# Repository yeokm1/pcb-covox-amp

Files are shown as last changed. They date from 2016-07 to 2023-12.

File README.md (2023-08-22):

# pcb-covox-amp
A tiny sound card based on the Covox Speech Thing design which includes an LM386 amplifier. I have another design that just has the resistor ladder portion only without the amplifier which can be found [here](https://github.com/yeokm1/pcb-covox).

##PCB Design software and addons used

1. Kicad 4.0.2 or later

## Video

(https://www.youtube.com/watch?v=iOxOxpSg3WE)

Due to copyright problems in the music used, this video can only be viewed on a PC. It is blocked on mobile devices and other platforms.

## Images
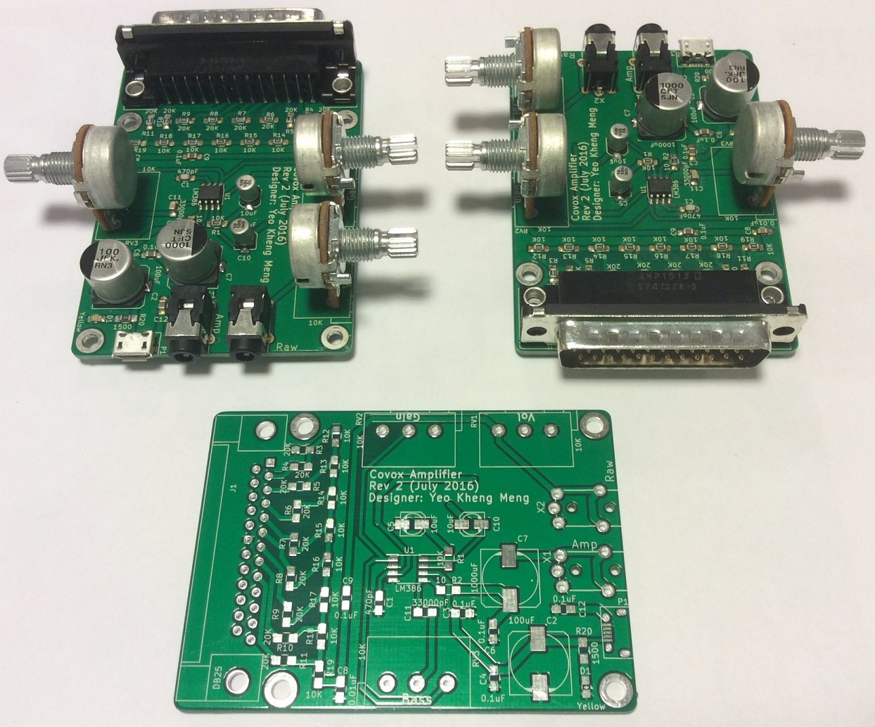
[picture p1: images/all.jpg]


The picture is of the Rev 2 version with the bug in the limited parallel port grounding. This has been corrected in the Rev 3 gerber but not fabricated.

##Schematic drawings

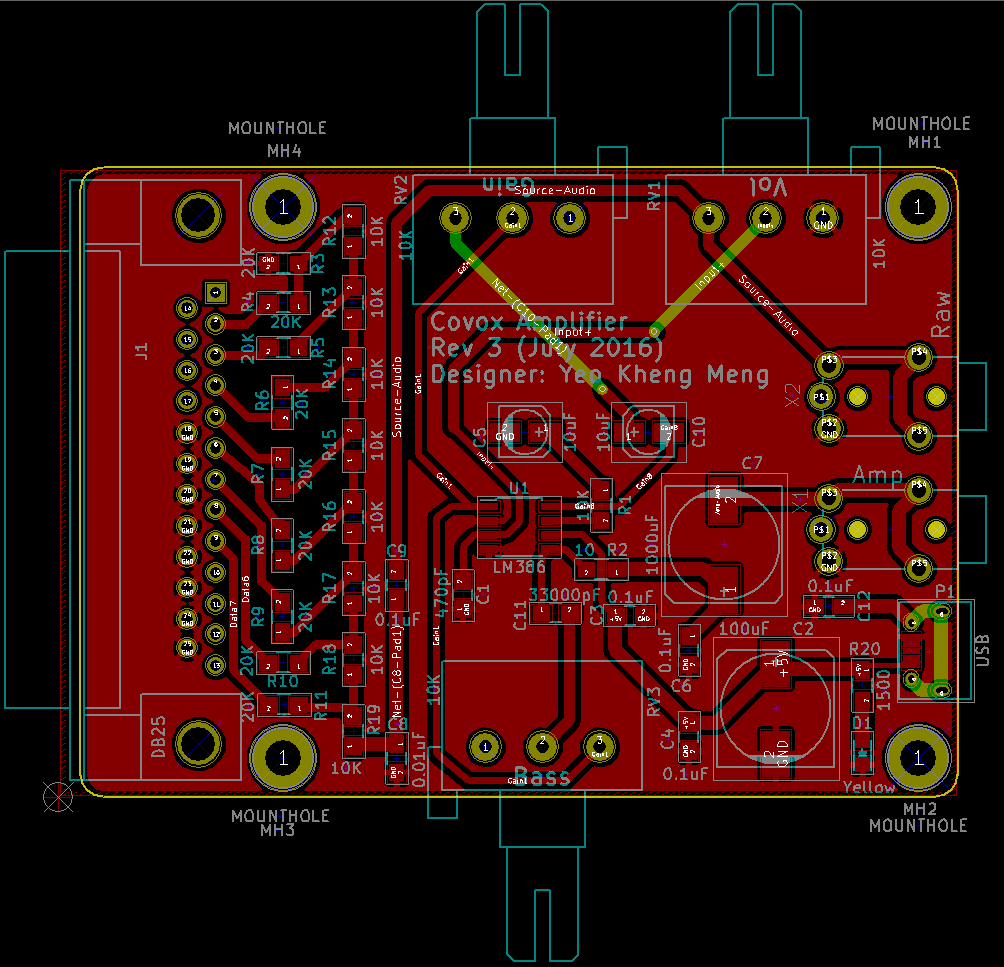
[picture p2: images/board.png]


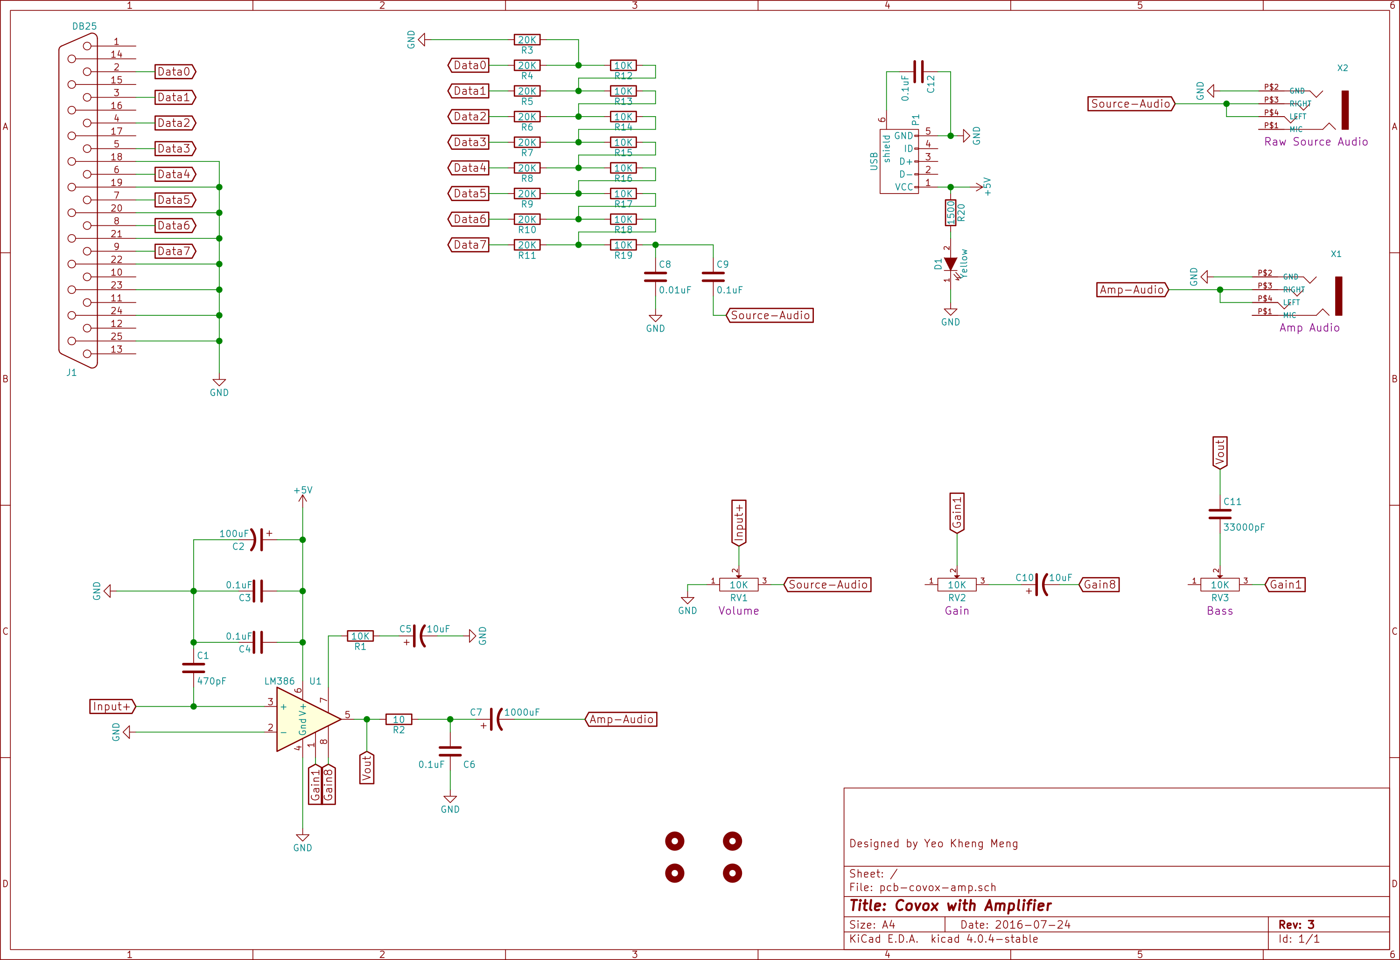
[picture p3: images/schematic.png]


## Parts required
Use Libreoffice to open [pcb-covox-amp-bom.ods](pcb-covox-amp-bom.ods)

## Errata

As reported in this [issue](https://github.com/yeokm1/pcb-covox-amp/issues/2), there is a mistake in components R2 and C6. As I'm not currently using this project, I'll not be correcting this error.

## References
1. [Hardware implementation references](https://blog.frantovo.cz/c/307/DAC%20%28zvukov%C3%A1%20karta%29%20pro%20LPT%20port%20a.k.a.%20Covox)
2. [Design reference](http://kb.gr8bit.ru/KB0010/GR8BIT-KB0010-Adding-multimedia-capability-covox-device.html)
3. [MJ-2135 package referenced from coqui-dip](https://github.com/open-eie/coqui-dip)
4. [Amplifier circuit](http://www.circuitbasics.com/build-a-great-sounding-audio-amplifier-with-bass-boost-from-the-lm386/)

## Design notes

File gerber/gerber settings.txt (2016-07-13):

Obtained from https://forum.kicad.info/t/creating-gerberfiles/1356/8

[plots]
plot format: gerber

layers:
F.Cu
B.Cu
B.SilkS
F.SilkS
B.Mask
F.Mask
Edge.Cuts
B.Paste (for stencil)
F.Paste (for stencil)

options:
Exclude PCB edge layer from other layers

gerber options:
Use Protel filename extensions
Include extended attributes

default line width (mm):
0.1

format:
4.6 (mm)

[drill file]
drill units:
Millimeters

zeroes format:
Decimal format

drill map file format:
Gerber

drill file options:
none (DESELECT merging of PTH and NPTH)

drill origin:
Absolute

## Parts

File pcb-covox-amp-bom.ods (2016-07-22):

Designator | Device | Package | Designation | Manufacturer | Part Number | Quantity | Unit Cost | Total Unit Cost | Source webpage
- | PCB Fabrication with stencil | 10cm x 10cm | HASL Lead free | Elecrow | - | 1 | 14 | 14 | http://www.elecrow.com/5pcs-2-layer-pcb-p-1174.html
C1 | SMD Multilayer Ceramic Capacitor | C_0805_HandSoldering | 470pF | AVX | 08055A471JAT2A | 1 | 0.162 | 0.162 | http://sg.element14.com/avx/08055a471jat2a/cap-mlcc-c0g-np0-470pf-50v-0805/dp/1612188
C3,C4,C6,C9,C12 | SMD Multilayer Ceramic Capacitor, MCU Series | C_0805_HandSoldering | 0.1uF | Multicomp | MCU0805F104ZCT | 5 | 0.008 | 0.04 | http://sg.element14.com/multicomp/mcu0805f104zct/cap-mlcc-y5v-100nf-50v-0805/dp/9406409RL
C8 | SMD Multilayer Ceramic Capacitor | C_0805_HandSoldering | 0.01uF | AVX | 08055C103KAT2A | 1 | 0.049 | 0.049 | http://sg.element14.com/avx/08055c103kat2a/cap-mlcc-x7r-10nf-50v-0805/dp/499225
C11 | SMD Multilayer Ceramic Capacitor | C_0805_HandSoldering | 33000pF | AVX | 08051C333KAT2A | 1 | 0.076 | 0.076 | http://sg.element14.com/avx/08051c333kat2a/cap-mlcc-x7r-33nf-100v-0805/dp/1833886
C2 | SMD Aluminium Electrolytic Capacitor, AEC-Q200 FT Series | c_elec_10x10.5 | 100uF, 63V | Panasonic Electronic Components | EEEFK1J101P | 1 | 1.49 | 1.49 | http://sg.element14.com/panasonic-electronic-components/eeefk1j101p/cap-alu-elec-100uf-63v-smd/dp/9696040
C5,C10 | SMD Aluminium Electrolytic Capacitor, AEC-Q200 FT Series | c_elec_4x5.3 | 10uF, 10V | Panasonic Electronic Components | EEE1AA100NR | 2 | 0.99 | 1.98 | http://sg.element14.com/panasonic-electronic-components/eee1aa100nr/cap-alu-elec-10uf-10v-smd/dp/2326096
C7 | SMD Aluminium Electrolytic Capacitor, AEC-Q200 FT Series | c_elec_10x10.5 | 1000uF, 16V | Panasonic Electronic Components | EEEFT1C102AP | 1 | 1.47 | 1.47 | http://sg.element14.com/panasonic-electronic-components/eeeft1c102ap/cap-alu-elec-1000uf-16v-smd/dp/2065974
J1 | Standard D Sub Connector, AMPLIMITE HD-20 Series, DB, Plug, 25 Contacts, Steel Body, Through Hole | DB25MC | DB25 | TE Connectivity/ AMP | 5747238-2 | 1 | 5.15 | 5.15 | http://sg.element14.com/te-connectivity-amp/5747238-2/d-sub-connector-plug-25pos/dp/2452364
D1 | LED, Yellow Green, SMD, 1.25mm x 1.4mm, 20 mA, 2 V, 575 nm | LED_0805 | Yellow, Green | Dialight | 5988160107F | 1 | 0.657 | 0.657 | http://sg.element14.com/dialight/5988160107f/led-0805-yellow-green-40mcd/dp/1465994
X1, X2 | Phone Audio Connector, Socket, 3.5 mm, 4 Contacts, PCB Mount | mj-2135-MJ-2135 | TRRS | Pro Signal | MJ-2135 | 2 | 3.79 | 7.58 | http://sg.element14.com/pro-signal/mj-2135/connector-rca-jack-3-5mm-tht-4way/dp/1267377
RV1,RV2,RV3 | Rotary Potentiometer | Potentiometer_Alps-RK163-single_15mm | 10K | BI Technologies/ TT Electronics | 16mm | 3 | 1.16 | 3.48 | http://sg.element14.com/bi-technologies-tt-electronics/p160kn-0qd15b10k/rotary-potentiometer-10kohm-16mm/dp/1782728
R1,R12,R13,R14,R15,R16,R17,R18,R19 | Surface Mount Chip Resistor, Thick Film, AEC-Q200 ERJ6E Series | R_0805_HandSoldering | 10K, ±0.5% | Panasonic Electronic Components | ERJ6RBD1002V | 9 | 0.047 | 0.423 | http://sg.element14.com/panasonic-electronic-components/erj6rbd1002v/res-thick-film-10k-0-5-0-1w-0805/dp/2380289
R2 | Thick Film Resistor | R_0805_HandSoldering | 10 | Panasonic Electronic Components | ERJ-6ENF10R0V | 1 | 0.156 | 0.156 | http://sg.element14.com/panasonic-electronic-components/erj-6enf10r0v/sistor-thick-film-10-ohm-125mw/dp/2284223
R3,R4,R5,R6,R7,R8,R9,R10,R11 | Surface Mount Chip Resistor, Thick Film, AEC-Q200 ERJ6E Series | R_0805_HandSoldering | 20K, ±0.5% | Panasonic Electronic Components | ERJ6RBD2002V | 9 | 0.047 | 0.423 | http://sg.element14.com/panasonic-electronic-components/erj6rbd2002v/res-thick-film-20k-0-5-0-1w-0805/dp/2380338
R20 | Thick Film Resistor | R_0805_HandSoldering | 1500 | Multicomp | MC0805S8F1501T5E | 1 | 0.005 | 0.005 | http://sg.element14.com/multicomp/mc0805s8f1501t5e/res-thick-film-1k5-1-0-125w-0805/dp/1632464
U1 | LM386M-1 Audio Power Amplifier, AB, 1 Channel, 325 mW, 4V to 12V | SOIC8 | LM386 | Texas Instruments | LM386M-1/NOPB | 1 | 1.48 | 1.48 | http://sg.element14.com/texas-instruments/lm386m-1-nopb/amp-power-audio-mono-class-ab/dp/1564701
P1 | USB Connector, Micro USB Type B, USB 2.0, Receptacle, 5 Ways, Surface Mount, Through Hole Mount | USB_Micro-B | Micro-USB | Hirose | ZX62D-B-5PA8(30) | 1 | 1.09 | 1.09 | http://sg.element14.com/webapp/wcs/stores/servlet/ProductDisplay?productId=141569308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
 |  |  |  |  |  |  | Subtotal | 25.711
 |  |  |  |  |  |  | GST 7% | 1.79977
 |  |  |  |  |  |  | Total (SGD) | 27.51077

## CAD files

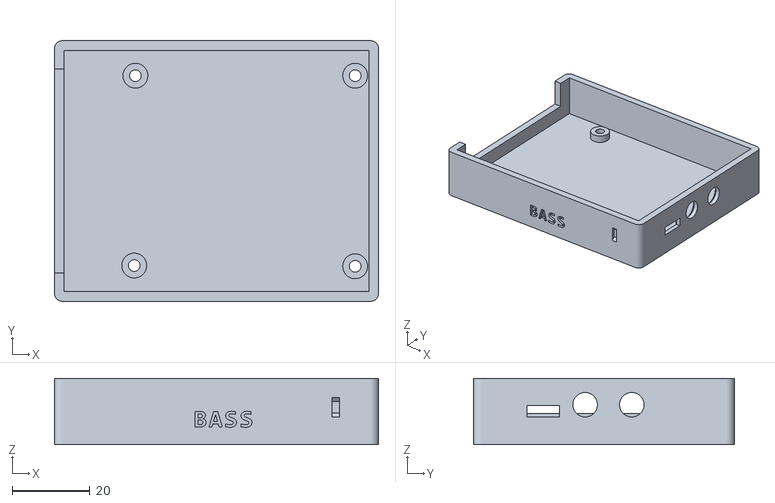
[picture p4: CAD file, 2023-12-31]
3d_printable_case/covox_amp_bottom.stl
83.3 x 67.0 x 17.0

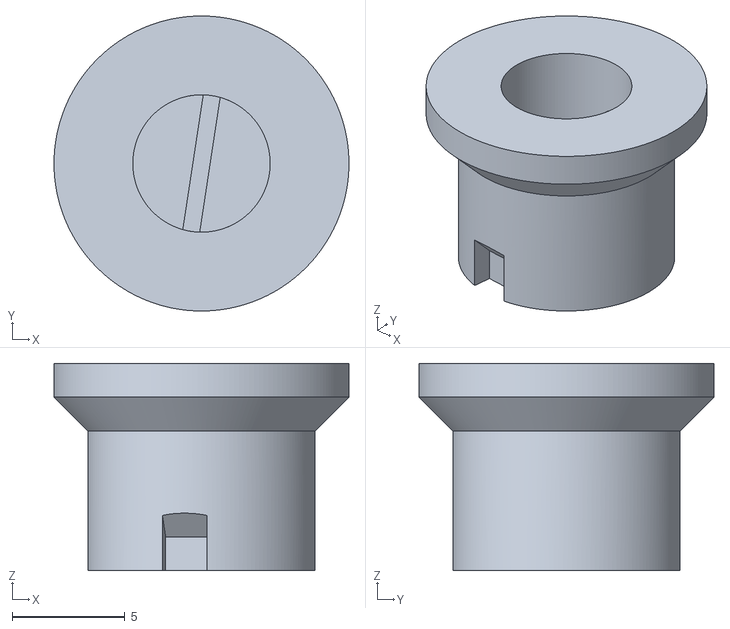
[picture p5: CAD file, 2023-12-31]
3d_printable_case/covox_amp_knob.stl
13.1 x 13.1 x 9.20

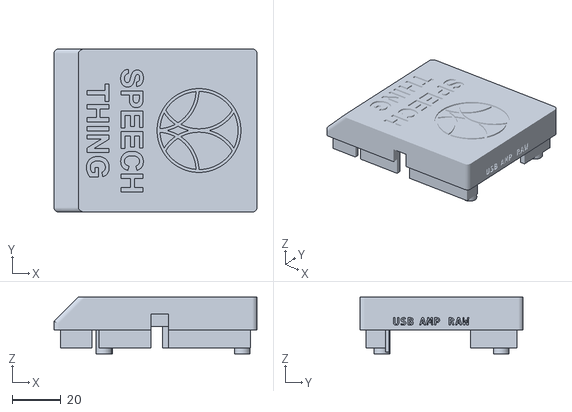
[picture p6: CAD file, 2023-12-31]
3d_printable_case/covox_amp_top.stl
83.3 x 67.0 x 23.4

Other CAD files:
3d_printable_case/covox_amp_3d_model.f3d

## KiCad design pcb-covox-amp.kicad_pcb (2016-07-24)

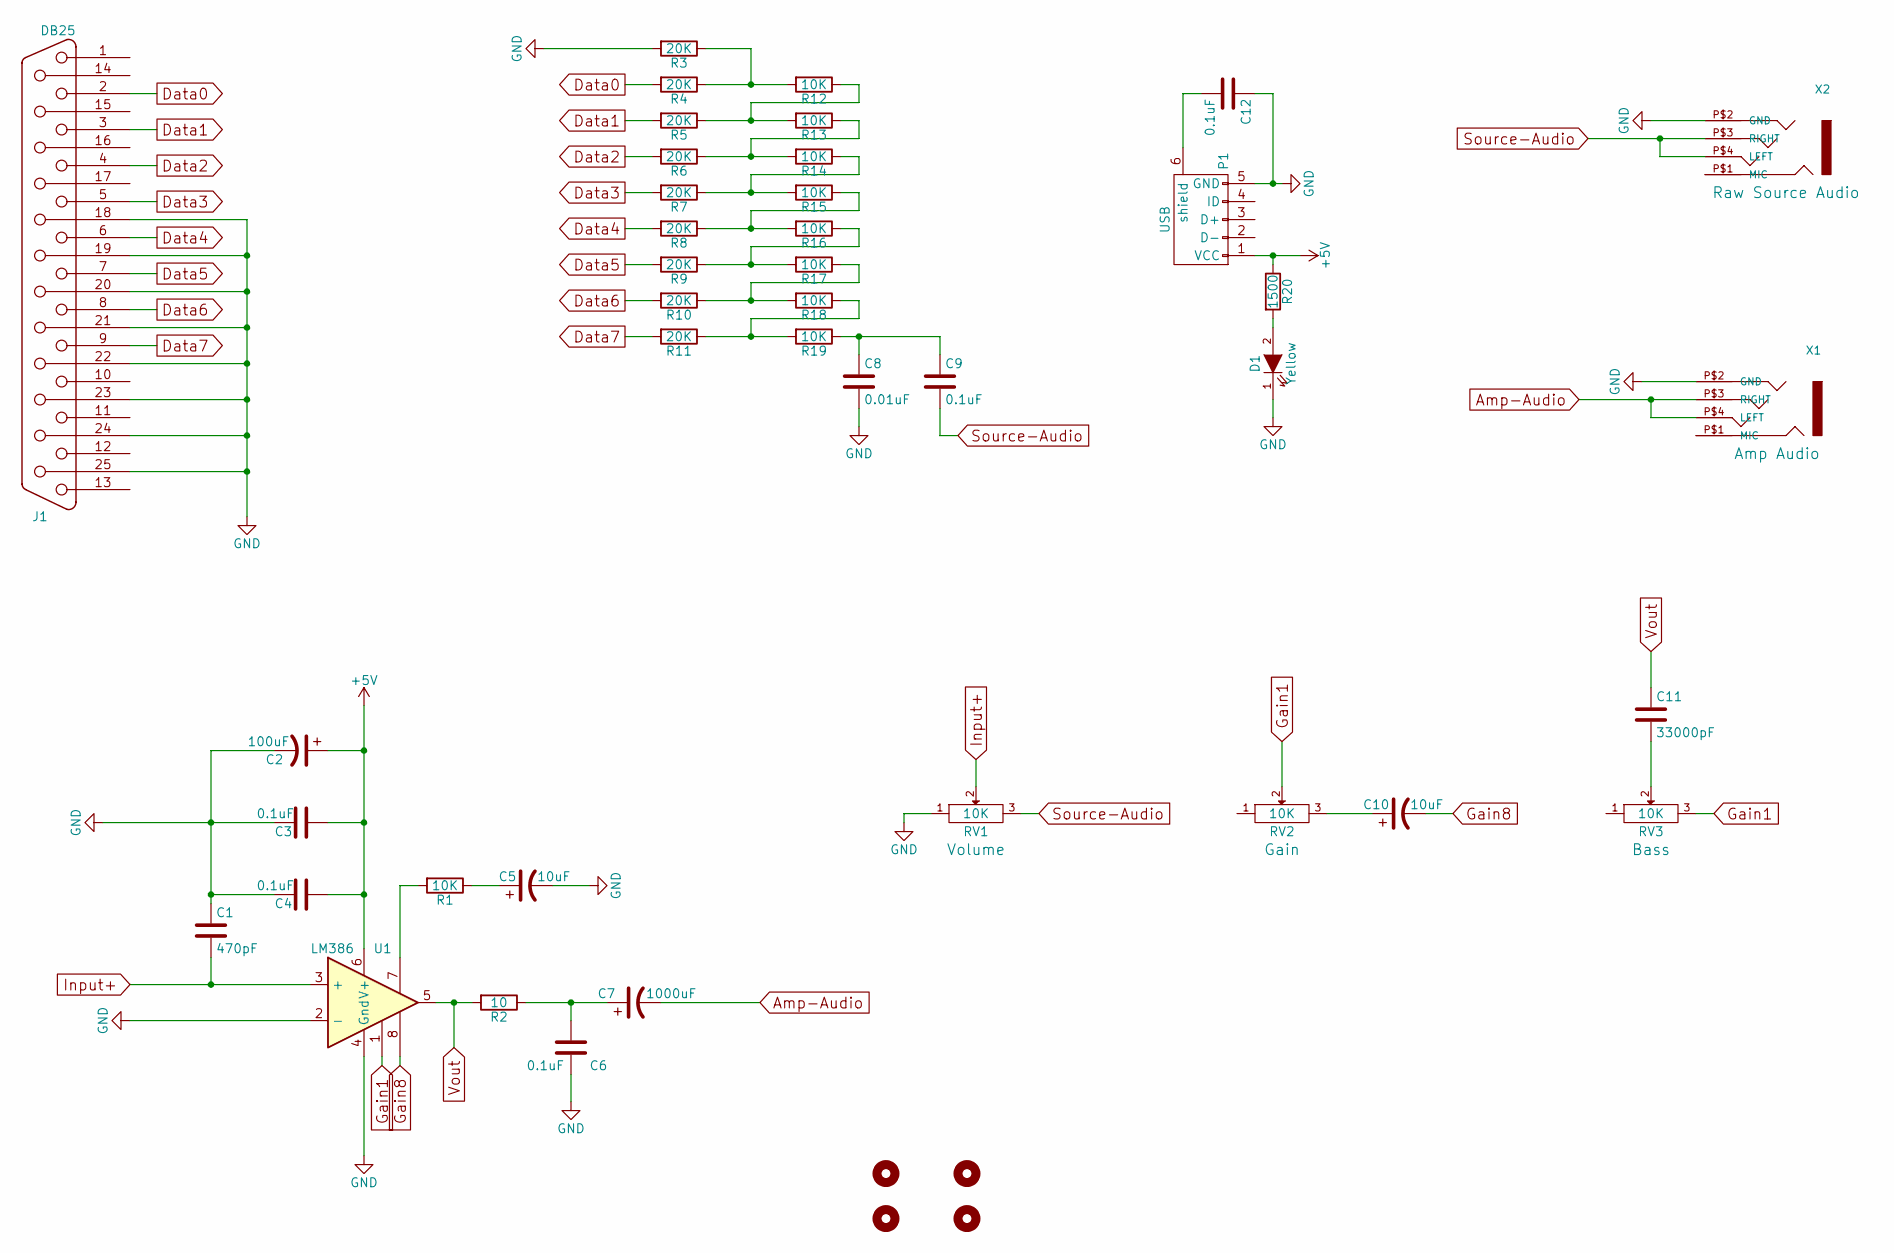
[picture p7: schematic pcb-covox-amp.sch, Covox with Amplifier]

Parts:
C1: 470pF; C_0805_HandSoldering
C2: 100uF; c_elec_10x10.5
C3, C4, C6, C9, C12: 0.1uF; C_0805_HandSoldering
C5, C10: 10uF; c_elec_4x5.3
C7: 1000uF; c_elec_10x10.5
C8: 0.01uF; C_0805_HandSoldering
C11: 33000pF; C_0805_HandSoldering
D1: Yellow; LED_0805
J1: DB25; DB25MC
MH1, MH2, MH3, MH4: MOUNTHOLE; MountingHole_3.2mm_M3_ISO14580_Pad
P1: USB; USB_Micro-B
R1, R12, R13, R14, R15, R16, R17, R18, R19: 10K; R_0805_HandSoldering
R2: 10; R_0805_HandSoldering
R3, R4, R5, R6, R7, R8, R9, R10, R11: 20K; R_0805_HandSoldering
R20: 1500; R_0805_HandSoldering
RV1, RV2, RV3: 10K; Potentiometer_Alps-RK163-single_15mm
U1: LM386; SOIC-8_3.9x4.9mm_Pitch1.27mm
X1: Amp; mj-2135-MJ-2135
X2: Raw; mj-2135-MJ-2135

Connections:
+5V: C2.1, C3.1, C4.1, P1.1 (VCC), R20.1, U1.6 (V+)
Amp-Audio: C7.2, X1.P$3 (RIGHT), X1.P$4 (LEFT), X1.P$5 (LEFT)
Data0: J1.2, R4.2
Data1: J1.3, R5.2
Data2: J1.4, R6.2
Data3: J1.5, R7.2
Data4: J1.6, R8.2
Data5: J1.7, R9.2
Data6: J1.8, R10.2
Data7: J1.9, R11.2
GND: C1.1, C2.2, C3.2, C4.2, C5.2, C6.2, C8.2, C12.1, D1.1 (K), J1.18, J1.19, J1.20, J1.21, J1.22, J1.23, J1.24, J1.25, P1.5 (GND), R3.2, RV1.1, U1.2 (-), U1.4 (Gnd), X1.P$2 (GND), X2.P$2 (GND)
Gain1: RV2.2, RV3.3, U1.1
Gain8: C10.2, U1.8
Input+: C1.2, RV1.2, U1.3 (+)
unnamed: C5.1, R1.1
unnamed: C6.1, C7.1, R2.1
unnamed: C8.1, C9.1, R19.1
unnamed: C10.1, RV2.3
unnamed: C11.2, RV3.2
unnamed: C12.2, P1.6 (shield)
unnamed: D1.2 (A), R20.2
unnamed: R1.2, U1.7
unnamed: R10.1, R17.1, R18.2
unnamed: R11.1, R18.1, R19.2
unnamed: R5.1, R12.1, R13.2
unnamed: R3.1, R4.1, R12.2
unnamed: R6.1, R13.1, R14.2
unnamed: R7.1, R14.1, R15.2
unnamed: R8.1, R15.1, R16.2
unnamed: R9.1, R16.1, R17.2
Source-Audio: C9.2, RV1.3, X2.P$3 (RIGHT), X2.P$4 (LEFT), X2.P$5 (LEFT)
Vout: C11.1, R2.2, U1.5

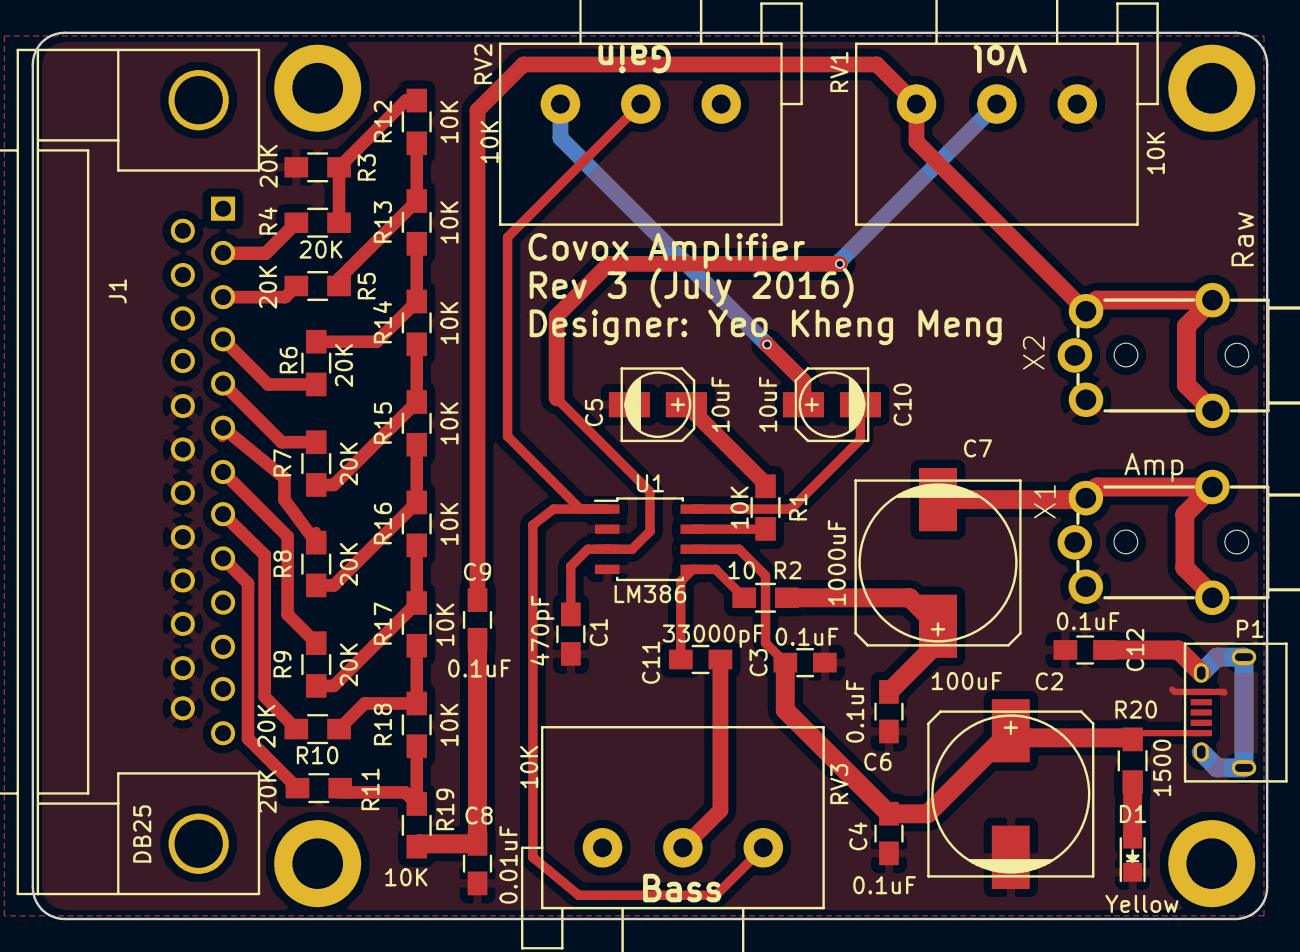
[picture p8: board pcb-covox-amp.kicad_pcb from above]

Board: 2 copper layers, 78.0 x 56.0 mm, 45 parts (0 on the bottom side), 32 nets.

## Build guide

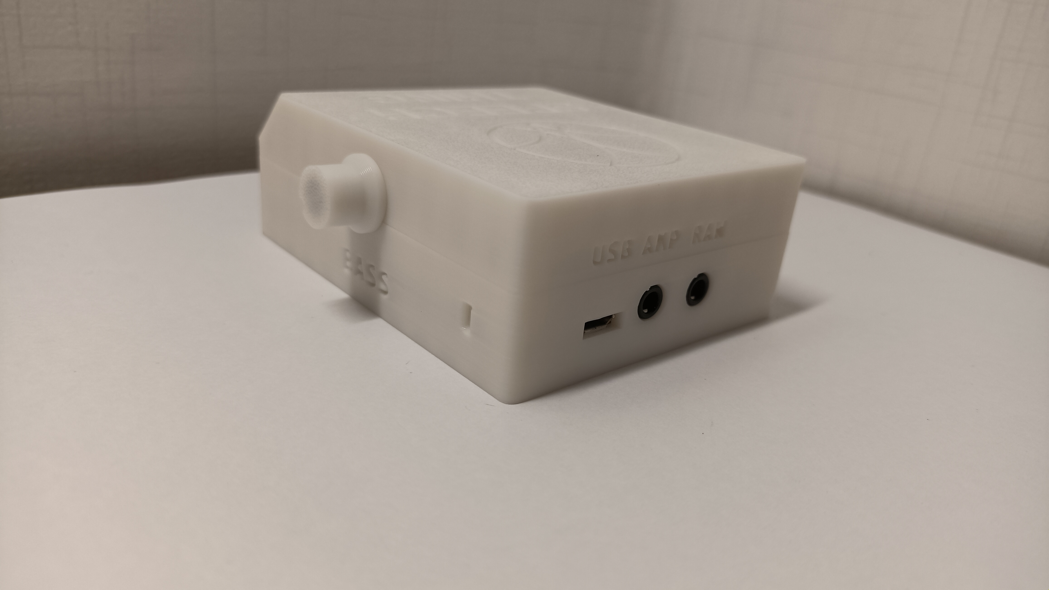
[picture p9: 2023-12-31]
3d_printable_case/images (3).jpg

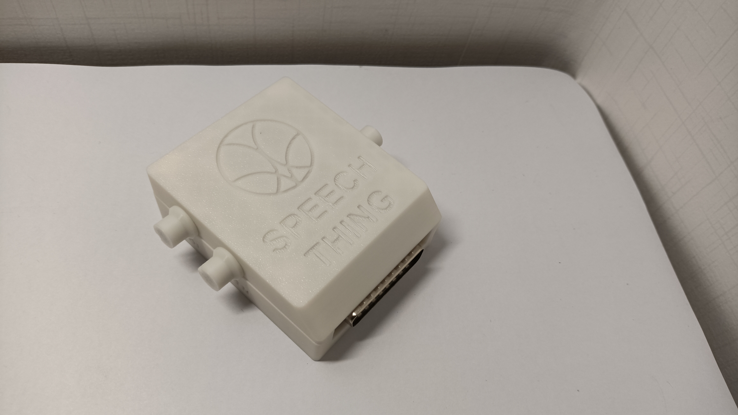
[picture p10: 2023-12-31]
3d_printable_case/images (2).jpg

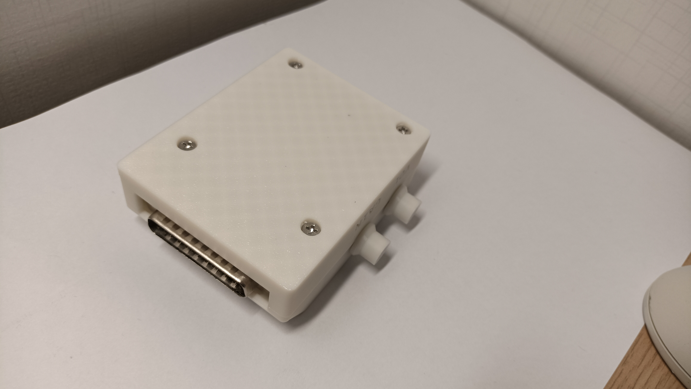
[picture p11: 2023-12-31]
3d_printable_case/images (4).jpg

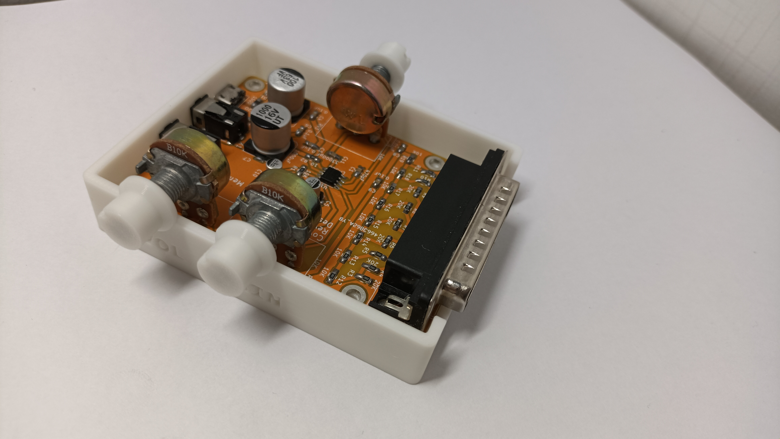
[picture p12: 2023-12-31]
3d_printable_case/images (1).jpg

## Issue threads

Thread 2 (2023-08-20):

Placement of R2 and C6

SukkoPera, 2023-08-20:
Hi, first of all thanks for sharing your work!

I noticed that in your amplifier circuit, you took the output between R2 and C6:

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

while in Scott's original circuit, R2 and C6 were placed in series between the output and ground (here R1 and C2):

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

Can you explain which was the reason for that?

yeokm1, 2023-08-22:
Oh yes, I think this is a mistake. I made this design 7 years ago 😅.

I don't think I will be fixing this mistake as I'm no longer using this project. But let me push a commit soon to explain the error.

SukkoPera, 2023-08-22:
Oh ok, easy explanation then :). Thanks!

yeokm1, 2023-08-22:
Mentioned this error in https://github.com/yeokm1/pcb-covox-amp/commit/813d431af90dc4b4537550a7beac57e9556295ce

Closed 2023-08-22.

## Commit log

2016-07-02 another commit
    [pcb-covox-amp.kicad_pcb, pcb-covox-amp.sch]
2016-07-02 curve corners
    [pcb-covox-amp.kicad_pcb, pcb-covox-amp.sch]
2016-07-02 silkscreen details
    [pcb-covox-amp.kicad_pcb]
2016-07-02 rev 1 gerber
2016-07-03 add mounting holes rev 2
    [pcb-covox-amp.kicad_pcb, pcb-covox-amp.sch]
2016-07-11 some adjustments
    [pcb-covox-amp.kicad_pcb]
2016-07-11 update db25 package
    [pcb-covox-amp.kicad_pcb, pcb-covox-amp.sch]
2016-07-11 rev2 gerber
    [pcb-covox-amp.kicad_pcb]
2016-07-13 adjust foot print
    [pcb-covox-amp.kicad_pcb, pcb-covox-amp.sch]
2016-07-13 adjust add pot direction
    [pcb-covox-amp.kicad_pcb, pcb-covox-amp.sch]
2016-07-13 rev 2 gerber
2016-07-22 adjust package size for 10uF capacitor
    [pcb-covox-amp-bom.ods]
2016-07-24 assign all parallel pout ground pins and rev 3
    [pcb-covox-amp.kicad_pcb, pcb-covox-amp.sch]
2017-01-02 higher res schematic image
2023-12-11 Add a 3D model for covox amp
    it's poor but usable.
    [covox_amp_3d_model.f3d, covox_amp_bottom.stl, covox_amp_knob.stl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]
